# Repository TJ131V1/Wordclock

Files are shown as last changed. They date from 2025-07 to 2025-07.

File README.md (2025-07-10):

## 💡 Project Description

**This repository contains all the files for my custom word clock project, inspired by QLOCKTWO EARTH 45.**
The clock is a fully functional, physical word-based timepiece built from scratch and controlled by an Arduino Nano. It includes four hidden capacitive touch sensors. In addition to telling the time, it features:

- Snake game

- Tetris game

- LED visual effects including custom scrolling text, Conway’s Game of Life, Matrix rain, and a random letter decay animation

The repository includes:

- **Arduino Code** – All source code for the microcontroller

- **KiCAD Files** – Complete circuit schematic and PCB layout

- **2D Cutting Files** – Laser-cut design files for the structural components

- **Technical Report** – In-depth 10-page report detailing the project design, implementation, and build process

## 📽️ Showcase Video (Click Thumbnail to View)

Watch the video (https://youtu.be/x_0dHoGPLj4)

## 📸 Product Pictures

<p align="center">

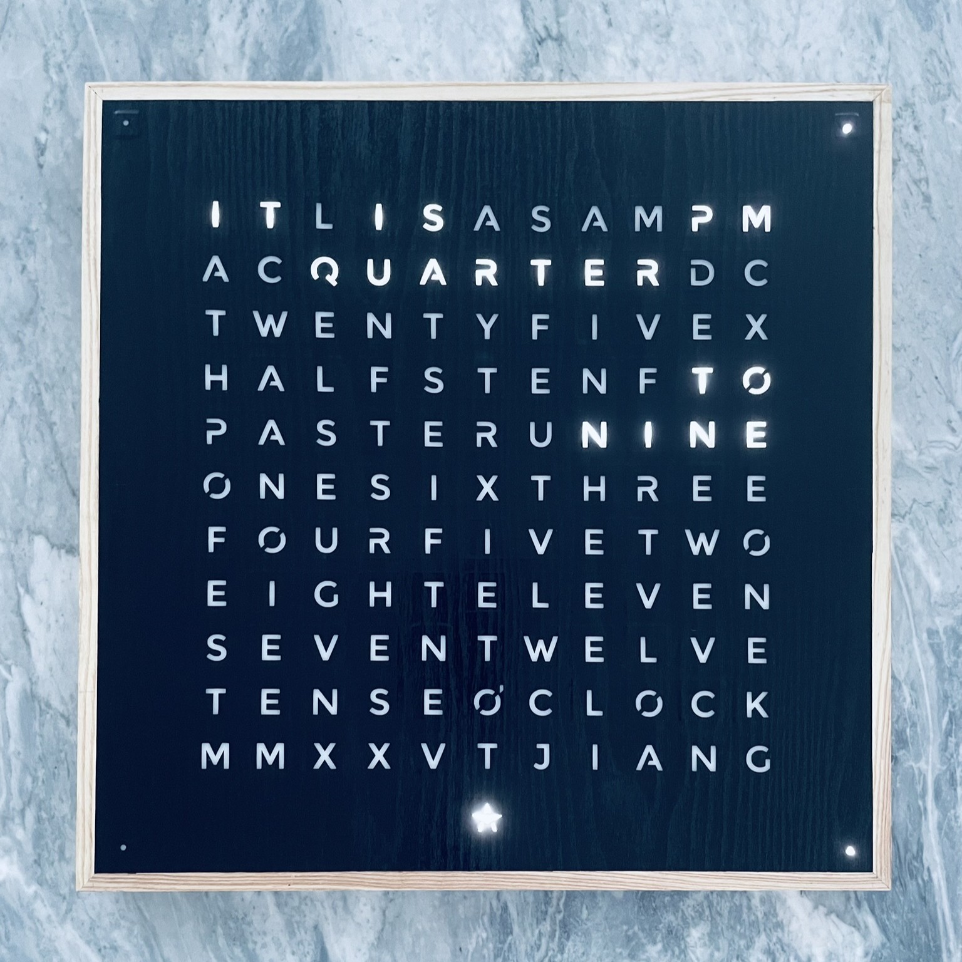
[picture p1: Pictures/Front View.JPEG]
Front view of the word clock
  

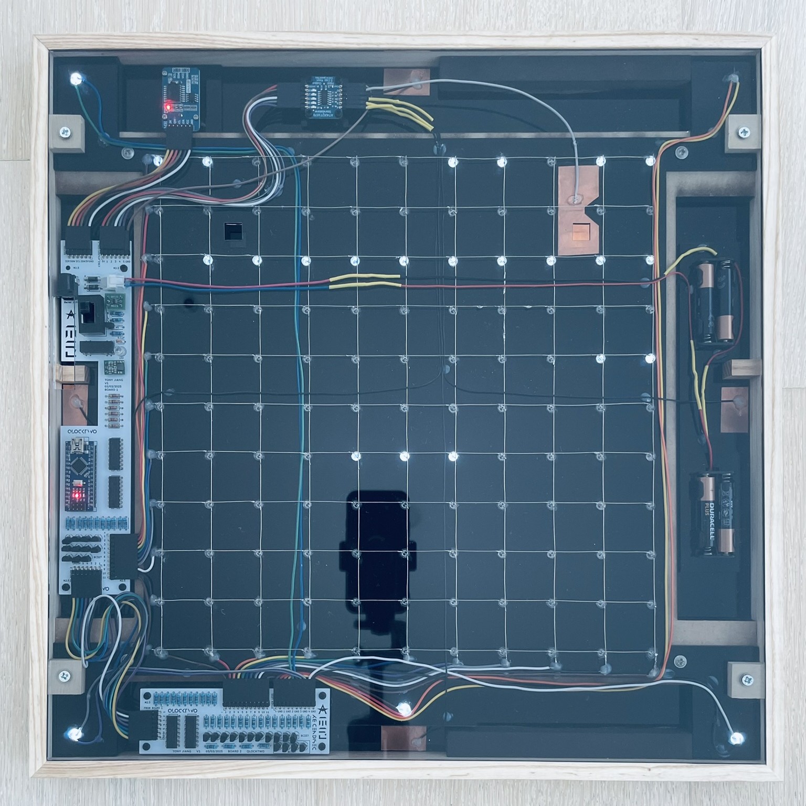
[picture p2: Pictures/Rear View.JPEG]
Rear view of the word clock
  

</p>

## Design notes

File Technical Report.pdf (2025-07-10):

Paper Produced for Institution of Electronics

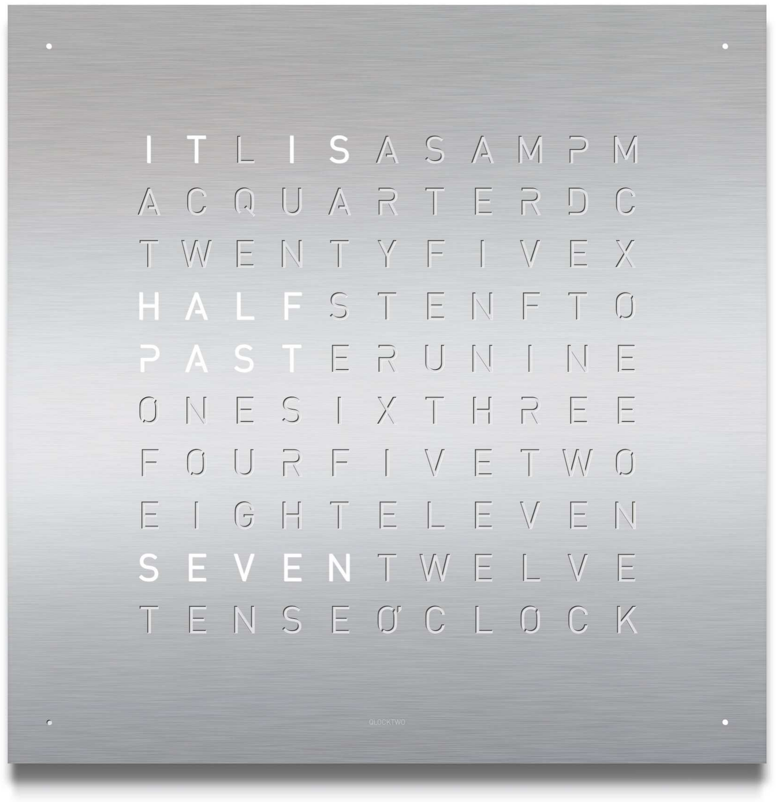
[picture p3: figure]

Tony Jiang, Winchester College, Winchester | Page 1

## An Arduino Word Clock

Tony Jiang, Winchester College, Winchester, Hampshire, SO23 9NA

### 1. Introduction

This project was a personal initiative that I undertook in my spare time between January and July 2025. At my school, there was a gifted QLOCKTWO EARTH 45 (a designer word clock) mounted on the wall. However, it had been non-functional for over five years. Only a few sta2 members recalled ever seeing it in operation; for most, it appeared to be nothing more than a decorative object. I discovered that the cost of professional repair was prohibitively high, to the extent that purchasing a new unit would be more economical. This realization motivated me to design and build my own word clock, incorporating custom features and functionality, all at a fraction of the commercial price. My goal was to install my fully functioning version at the school as a practical and symbolic replacement.

Figure 1.1 shows a QLOCKTWO EARTH 45 STAINLESS STEEL, the same model present at my school.¹

### 2. The Problem to be Solved

This project aims to design and manufacture a 45 × 45 cm word clock that not only displays the time but also incorporates a range of custom features. These include the ability to play classic games such as Snake and Tetris on its LED matrix, as well as the capability to show scrolling text and dynamic LED e2ects for aesthetic purposes. Achieving this functionality requires precise control of each individual LED within the matrix, along with a reliable timekeeping system that can maintain accuracy even when the device is disconnected from a power source. To enhance usability and flexibility, the clock is designed to operate on both battery and mains power. Interactive features are enabled through the integration of appropriate input sensors.

Tony Jiang, Winchester College, Winchester | Page 2

In addition to functionality, aesthetic considerations play an important role in the design. The target thickness for the final product is less than 25 mm, closely aligning with the original
QLOCKTWO design, which has a main body thickness of approximately 20 mm. It is worth noting that the QLOCKTWO also includes a secondary, smaller rear housing — presumably containing the microprocessor and other electronics — which may allow for a slimmer front profile. This project aims to achieve a similarly sleek form factor while housing all required components internally.

### 3. Research

### 3.1 LED Control

Controlling each individual LED in the matrix is a central technical challenge in this project. Through online research, I found that a common approach involves configuring the matrix so that the rows act as anodes and the columns as cathodes. This setup enables the use of multiplexing — a technique where only one row (or column) is activated at a time, while rapidly cycling through all rows (or columns) fast enough that, due to persistence of vision, it appears as though all desired LEDs are lit simultaneously.

The original QLOCKTWO uses a 10×11 LED matrix to accommodate all the necessary words. In my design, I have employed an 11×11 LED matrix to create a more symmetrical display and to provide additional space for customizing the letters. However, this larger matrix requires 22 I/O ports for direct control — 11 for the rows and 11 for the columns. The Arduino Nano unfortunately o2ers only 14 digital I/O pins, many of which are reserved for other functions. To address this limitation, I will use shift registers such as the 74HC595 to expand the number of available outputs. Each 74HC595 shift register controls 8 outputs while requiring only 3 Arduino pins (data, clock, and latch). However, an additional I/O pin is needed to control the shift registers’ clear (reset) line. By daisy-chaining two pairs of shift registers — one pair dedicated to the rows and the other to the columns — I will be able to control up to 32 outputs using just 7 Arduino pins. This configuration enables e2icient and scalable management of the 121 LEDs in the matrix while conserving valuable I/O resources on the microcontroller.

The word clock also includes five additional LEDs: one for illuminating the logo and four at the corners to indicate the minute modulus (as the matrix displays time in 5-minute intervals). Since I have unused outputs on the shift registers, I connected the corner LEDs to these outputs. I also decided that the logo LED should be wired directly to the microcontroller to simplify the coding.

### 3.2 Timekeeping

To ensure accurate timekeeping, I chose to use a separate RTC (Real-Time Clock) module with its own battery backup, as recommended by online research. The module communicates with the microcontroller via I²C and maintains accurate time even when the main power is disconnected. I

chose the AZ-Delivery DS3231, as it was readily available on Amazon.

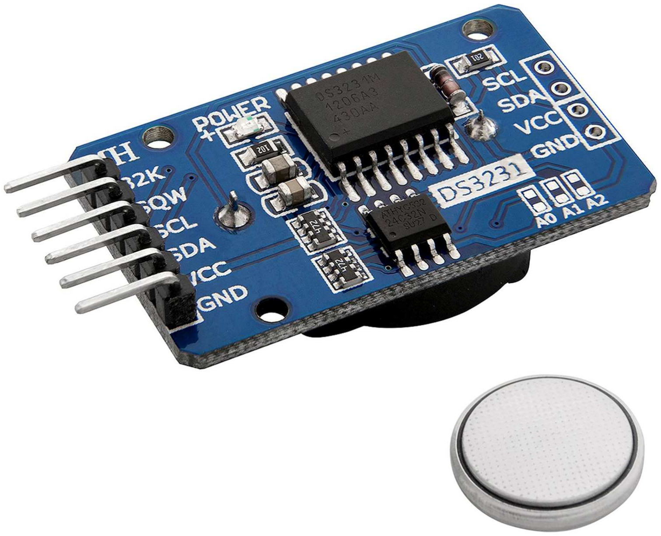
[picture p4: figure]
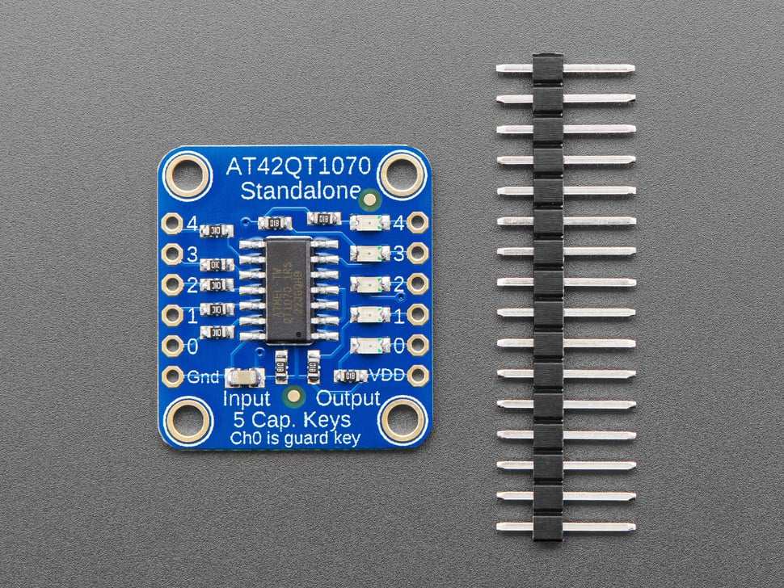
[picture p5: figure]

Tony Jiang, Winchester College, Winchester | Page 3

Figure 3.1 shows the AZ-Delivery DS3231 Real-Time Clock (RTC) module, with its 3.3V battery.²

### 3.3 Input Sensor

To enable gameplay features such as Snake and Tetris, I will need four input buttons positioned near the edges of the word clock. For aesthetic reasons, I want these buttons to remain hidden from view. Recalling that some lamps use touch-sensitive controls, I researched ways to implement invisible inputs and quickly discovered the presence of capacitive touch sensors.

Capacitive touch sensors detect changes in capacitance caused by a conductive object. When a finger nears the surface, it alters the local electric field, which the sensor detects and registers as a touch input. Looking for ways to implement this in my project, I found the Adafruit AT42QT1070 5-Pad Capacitive Touch Sensor. This standalone module communicates with the microcontroller via parallel output, pulling the corresponding channel LOW upon detection of a touch, making it straightforward to integrate into my design. I simply need to attach copper plates to the reverse side of the surface where input is desired and connect the plates to the sensor chip.

Figure 3.2 shows the Adafruit AT42QT1070 Standalone 5-Pad Capacitive Touch Sensor.³

### 3.4 Power

Since the 126-LED word clock must operate on both battery and mains power, a dedicated voltage regulator separate from the Arduino Nano is necessary. The Arduino cannot directly power such a large number of LEDs. I selected the Pololu 5V 1A Step-Up/Step-Down Voltage Regulator (S13V10F5), which provides a stable 5V output from input voltages ranging between 3V and 22V. For the battery, I plan to use four AAA cells in series. To protect the circuit from damage caused by excessive battery drain, a voltage supervisor is required to disconnect power when voltage falls below a safe threshold. I chose the Texas Instruments TPS3710 IC for this function. The TPS3710

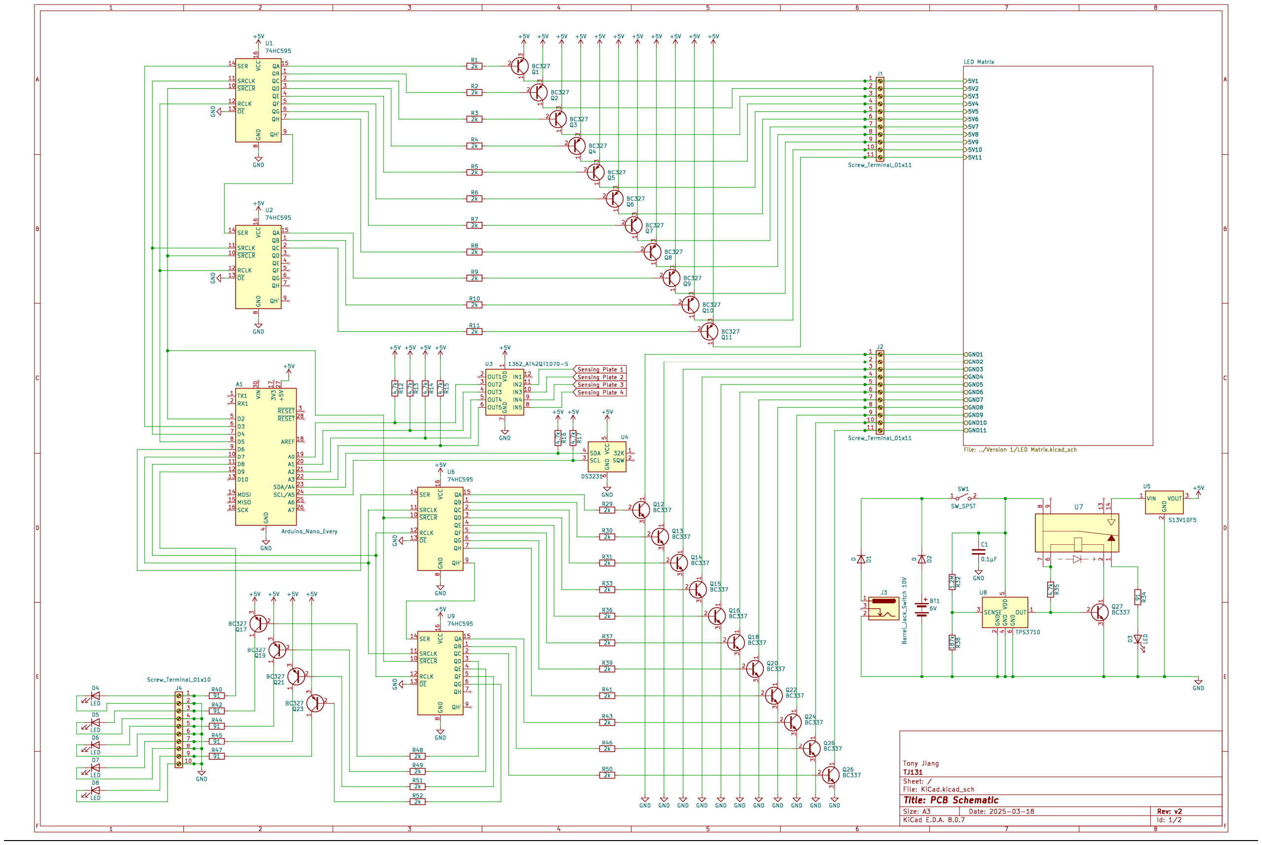
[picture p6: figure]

Tony Jiang, Winchester College, Winchester | Page 4

outputs a LOW signal when the input voltage falls below a pre-set threshold. When integrated into a custom circuit, this output can be used to disconnect the circuit.

### 4. Design and Build

### 4.1 Schematic

Figure 4.1 shows the schematic of the entire word clock.

Each LED in the matrix is arranged such that all anodes in a given row are soldered together, and all cathodes in a given column are connected. A PNP transistor is placed before each row to switch the row on or o2, while an NPN transistor is placed after each column to switch the column on or o2. This configuration allows control of any individual LED by activating its corresponding row and column transistors. It also enables each LED to draw current directly from the power source, while still being controlled via the Arduino.

Although the LEDs are rated for 3V, they are powered at 5V because multiplexing across the 11×11 matrix limits the time each LED is active, e2ectively reducing the average current through each one by a factor of 11. All LEDs are therefore wired in parallel to the 5V line.

Each transistor base is controlled by a 74HC595 shift register, which converts the Arduino’s serial output into parallel control signals. A 2 kΩ resistor is placed between each shift register output and transistor base to limit base current and protect the components.

Tony Jiang, Winchester College, Winchester | Page 5

A similar PNP-based switching method is used to control the four corner LEDs, which indicate minutes between the five-minute intervals. However, since these LEDs are not multiplexed, a 91 Ω resistor is added to each to keep the current within safe limits. The logo LED is connected directly to an Arduino I/O pin, also with a 91 Ω resistor for current limiting.

The RTC module (DS3231) requires two additional ports — Serial Data (SDA) and Serial Clocl (SCL) — for communication via the I²C protocol. I²C is an open-drain communication protocol where

devices can only pull the line LOW; HIGH signals are achieved through external pull-up resistors, which ensure the lines return to a HIGH state when not being pulled LOW. Although the DS3231 module includes built-in pull-up resistors, I added external ones in my circuit as an extra precaution to ensure signal reliability.

The remaining Arduino I/O ports are connected to the Adafruit AT42QT1070 capacitive touch sensor. Although the chip supports five inputs, I only required four sensor plates — one for each invisible button — so I connected four of its output lines to the Arduino. As mentioned earlier, the sensor uses open-drain outputs: it pulls the corresponding line LOW when a touch is detected. To ensure the lines return to a HIGH state when not pulled LOW, I added external pull-up resistors to each connection.

In total, I used 14 signal pins on the Arduino: 8 for the LEDs, 2 for the RTC module, and 4 for the capacitive touch sensor.

The final part of the circuit is the power module, located in the bottom corner of Figure 4.1. The S13V10F5 regulator converts any input voltage between 3V and 22V into a stable 5V output. A reed relay (U7) is used to disconnect the power supply from the main circuit if the input voltage drops too low. This cuto2 mechanism is controlled by the TPS3710 voltage monitor, which constantly measures the voltage at its SENSE pin. If the sensed voltage falls below 0.4V, the TPS3710 pulls its open-drain OUT pin LOW. To ensure the OUT pin returns to a HIGH state when not asserted, a pull-up resistor is required.

Since the TPS3710 only detects whether the voltage is above or below 0.4V, a potential divider is used to scale the input voltage accordingly. By selecting resistor values that make the SENSE pin read exactly 0.4V when the input voltage reaches the desired cuto2 threshold, the TPS3710 can e2ectively monitor supply levels. The appropriate resistor values were calculated using equations from the Texas Instruments application report⁴

and the TPS3710 datasheet⁵ , rounded to the
nearest standard resistor values.
-=

|%

100

− 1

=

3.00V 1
100

# 25nA 3.00V

0.400V − 1

= 185kΩ | 4.1!

" = -#

# − 1$ = 185kΩ # 3.00V

0.400V − 1$ = 1.2MΩ | 4.2!

When used in conjunction with an NPN transistor, this circuit cuts o2 current to the relay coil if the input voltage is too low, because when the OUT pin is asserted (pulled LOW), the transistor is switched o2, preventing current from flowing through the relay magnet. This causes the reed switch to disconnect the main circuit and instead complete a path to an LED, which lights up to

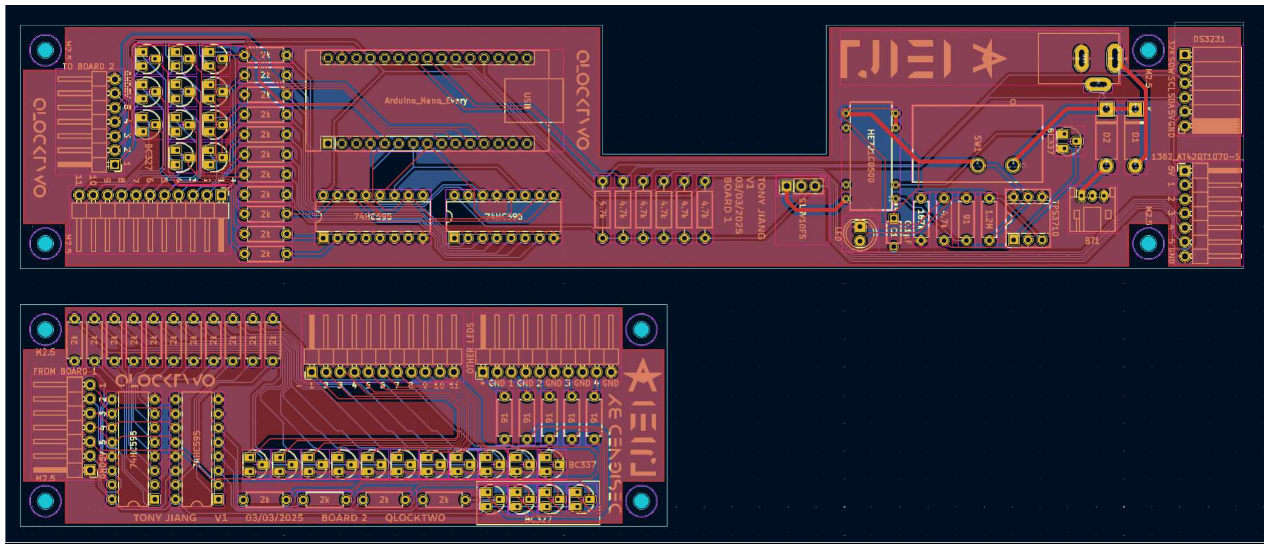
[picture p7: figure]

Tony Jiang, Winchester College, Winchester | Page 6

indicate that the input voltage has fallen below the threshold — either due to low mains voltage or a depleted battery.

### 4.2 PCB Layout

Figure 4.2 illustrates the layout of the custom PCB manufactured for the word clock.

The components from the schematic are distributed across two custom-designed PCB boards. The main challenge in the PCB layout was fitting all components within the limited internal space of the word clock, which has a maximum thickness of 25 mm. The central area is occupied by the LED matrix, leaving only narrow strips along the four edges for electronics. Additionally, the presence of corner LEDs and capacitive touch pads further reduces the space available to mount the PCB boards. On Board 1, there is a central cutout in the PCB to accommodate a copper plate acting as a touch sensor, located at the midpoint of each edge. Various pin headers connect the PCB to the rest of the components:

- On Board 1, the two right-side pin header rows connect the Arduino to the RTC module and capacitive touch sensor.
- The header orientated downwards on Board 1 connects to the anodes of the LED matrix.
- The left-side headers on both boards are wired together to allow communication between the boards.
- On Board 2, the headers oriented upwards connect to the cathodes of the LED matrix and the five additional LEDs (four minute indicators and the logo LED).

The PCB Gerber files were sent to JLCPCB for physical fabrication, which arrived by post within a week.

### 4.3 Physical Fabrication

The physical fabrication of the product primarily involved laser cutting, supplemented by some woodworking for structural components.

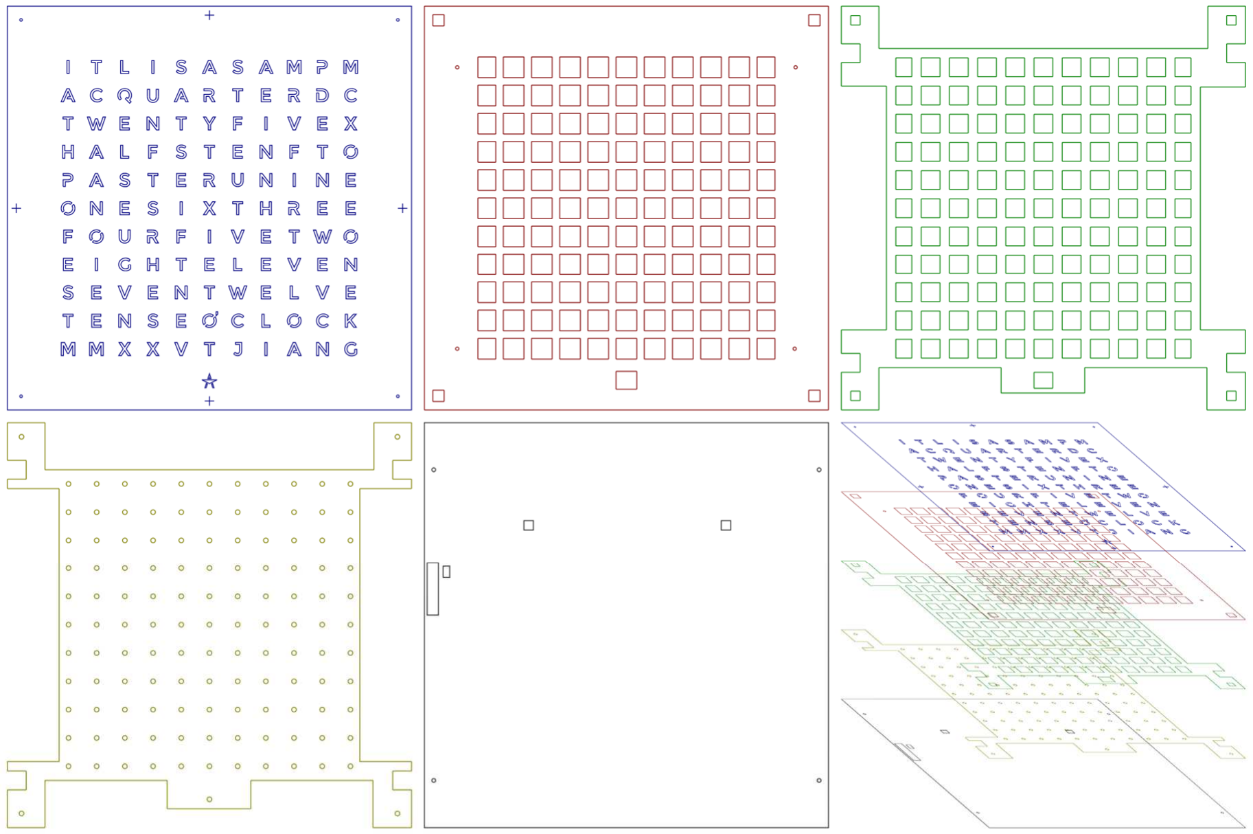
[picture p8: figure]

Tony Jiang, Winchester College, Winchester | Page 7

Figure 4.3 illustrates the various structural layers of the word clock. The clock consists of a 0.5 mm vinyl faceplate (blue), 3 mm acrylic light-di2user layer (red), 9 mm MDF structural layer (green), 3mm acrylic
LED structure layer (yellow), and a 3mm back plate (black).

Figure 4.3 shows all the laser-cut layers used in the construction of the word clock. The top blue layer is a sheet of black woodgrain-patterned vinyl with cut-out letters. The cut-out letters are based on the Montserrat font, which I customized to ensure no islands appear within the letters.

The blue layer is adhered to the red layer beneath it, which is made from 3 mm black acrylic with letter-shaped cutouts filled with 3 mm semi-transparent white acrylic. This combination acts as a di2user, helping to evenly distribute the light from the LEDs below each letter.

The green layer is a 9 mm MDF structural component. It creates the necessary spacing between the di2user and the LED matrix and provides mounting points for both the red and yellow layers via screws.

The yellow layer is a 3 mm acrylic jig that accurately holds each LED in place within its designated hole.

At the back, the black layer is a 3 mm clear acrylic panel that protects the internal electronics. It includes holes for wall-mounting screws and a cutout on the left-hand side for a switch.

Additionally, four wooden support blocks are glued to the red layer and are slotted into cutouts in the green and yellow layers. These blocks allow the back panel to be securely screwed in while maintaining an air gap between the yellow and black layers — providing essential space for wiring and other electronics.

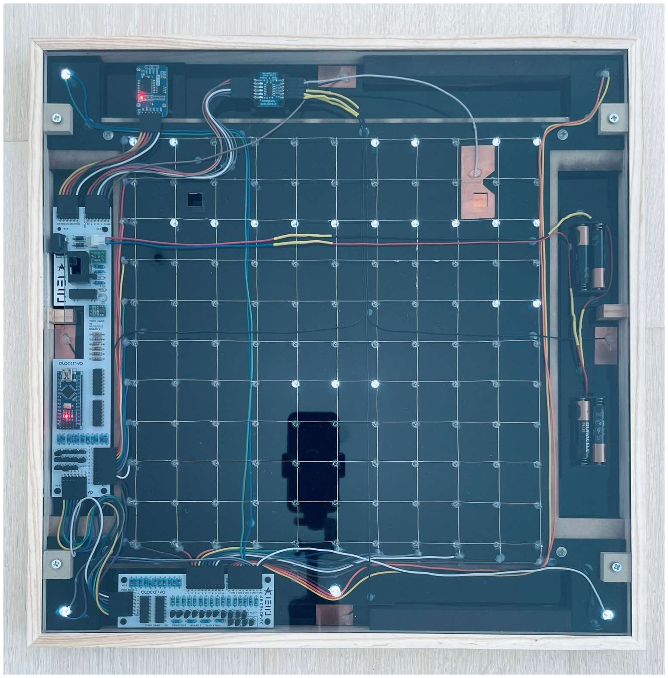
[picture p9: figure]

Tony Jiang, Winchester College, Winchester | Page 8

Lastly, a 10 mm thick ash wood frame is built around the clock, joined at the corners with mitre joints. This frame protects the entire structure from the sides and gives it a clean, finished look. The electronic components are mounted in the narrow spaces along the edges of the clock. Wires are soldered to connect the PCBs to the LEDs and copper touch plates. To keep the wiring secure and organized, hot glue is used to fix the wires in place. The internal layout of the electronics is shown in Figure 4.4, which is a backside view of the finished product.

Figure 4.4 shows the rear side of the completed word clock while in clock mode.

### 4.4 Code

Unfortunately, the full C++ code for this project exceeds 1,000 lines and cannot be fully explained within this document. However, the complete commented code — along with all CAD and design files — is available on the project’s GitHub page: https://github.com/TJ131V1/Wordclock.

In short, the code supports four main functions: time display, Snake, Tetris, and various LED e2ects. Long pressing the respective copper touch plates switches between modes. The same plates serve as control inputs for Snake and Tetris. In LED e2ects mode, users can toggle between several animations: Conway’s Game of Life, a Matrix-style rain e2ect, a random letter decay, and a scrolling text display (the text can be modified in the code).

### 5. Evaluation of Final Product

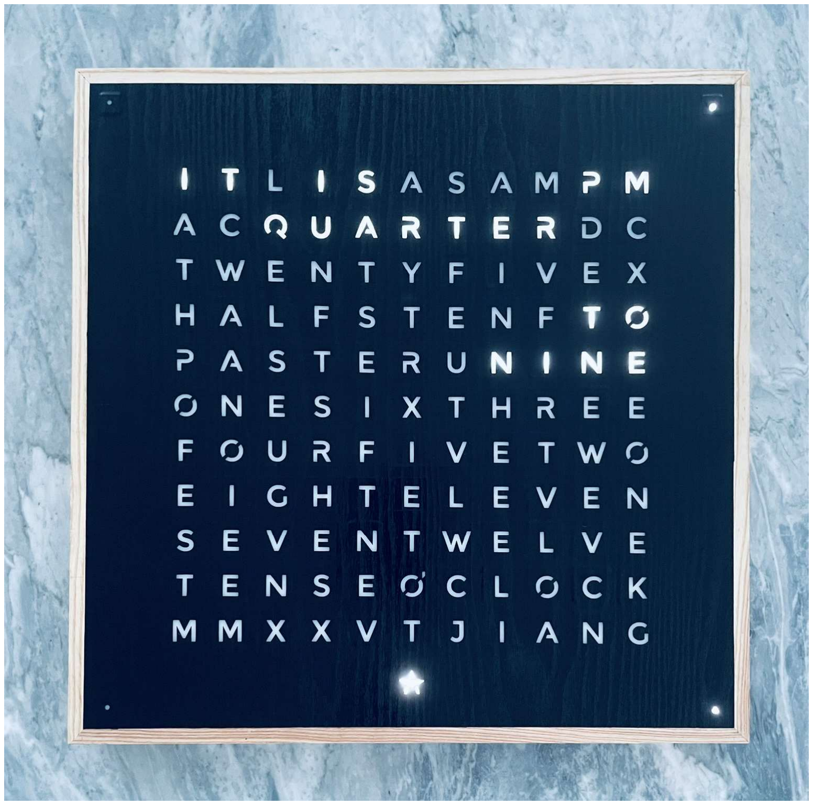
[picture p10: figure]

Tony Jiang, Winchester College, Winchester | Page 9

Figure 5.1 shows the front of the completed word clock, displaying the time 8:47 in clock mode.

The final product has a total thickness of exactly 25 mm, precisely meeting the original design specification. The front display is clean and aesthetically pleasing, and the timekeeping is highly accurate — only about one second behind the actual time. The capacitive touch buttons are extremely well hidden, making them virtually undetectable without prior knowledge of their placement. Gameplay for Snake and Tetris is smooth and responsive, o2ering a satisfying user experience. The various LED e2ects add dynamic visual interest, making the clock an eye-catching decorative piece when mounted. The ability to switch modes using capacitive touch sensors enhances usability and creates a seamless, intuitive interface. Overall, I’m very satisfied with the additional features beyond timekeeping — they make the clock both functional and engaging.

The PCB components cost approximately £40. Fabricating the PCB board cost £25 for a minimum batch of five, so in commercial production, the cost per clock would be under £5. The structural components were free, as I fabricated them at my school, but the materials used — acrylic sheets, MDF, and ash dowel — would likely cost under £20. Laser cutting is estimated at around £150 total. Altogether, this brings the total cost per clock to under £200, which is roughly 13% of the price of a QLOCKTWO EARTH 45.

### 6. Recommendations for Future Work

In hindsight, using multiplexing as the core architecture was not the best design choice. A chain of addressable LEDs would have greatly simplified both the schematic and PCB layout by eliminating

Tony Jiang, Winchester College, Winchester | Page 10

the need for shift registers and numerous transistors. Although more expensive than standard white LEDs, addressable LEDs o2er major advantages: full RGB colour control, much higher brightness, and more consistent illumination. In the current clock, the centres of the letters are noticeably brighter than the edges, and the display is di2icult to read in bright daylight — issues that brighter LEDs would solve. They would also drastically reduce code complexity. The primary reason for the lengthy code is the complexity introduced by the multiplexing architecture.

I also underestimated the small size of the TPS3710’s SOT-6 package (just 2.8 × 2.9 mm), which made soldering di2icult and time-consuming. For future revisions or commercial production, I would use a voltage supervisor in a larger DIP package.

Additionally, the clock should adjust for daylight saving time automatically, using date information from the RTC to stay accurate year-round in the UK.

Finally, the four AAA batteries only last around two hours. Switching to AA batteries would greatly improve runtime.

### 7. Acknowledgments

I would like to express my gratitude to Winchester College for providing access to the Design and Technology facilities. I am also sincerely thankful to the D&T teachers and technicians — Callum Barnes, Adrian Ahmed, Trevor Ward, and David Salter — for their invaluable support and guidance throughout the physical fabrication of this project.

### 8. References

1. QLOCKTWO Earth 45 Stainless Steel Wall Clock Watch QT4ENSS Watch | Jura Watches.

https://www.jurawatches.co.uk/products/qlocktwo-classic-stainless-steel-wall-clock-45cm-

fcenss.

2. Real Time Clock RTC DS3231 I2C Echtzeituhr kompatibel mit Arduino und Raspberry Pi. AZ-

Delivery https://www.az-delivery.uk/products/ds3231-real-time-clock.

3. Adafruit Industries Standalone 5-Pad Capacitive Touch Sensor Breakout - AT42QT1070.

https://www.adafruit.com/product/1362.

4. Fagnani, A. IQ vs Accuracy Tradeo2 In Designing Resistor Divider Input To A Voltage Supervisor.

(2011).

5. TPS3710 Wide VIN Voltage Detector datasheet (Rev. A). (2024).

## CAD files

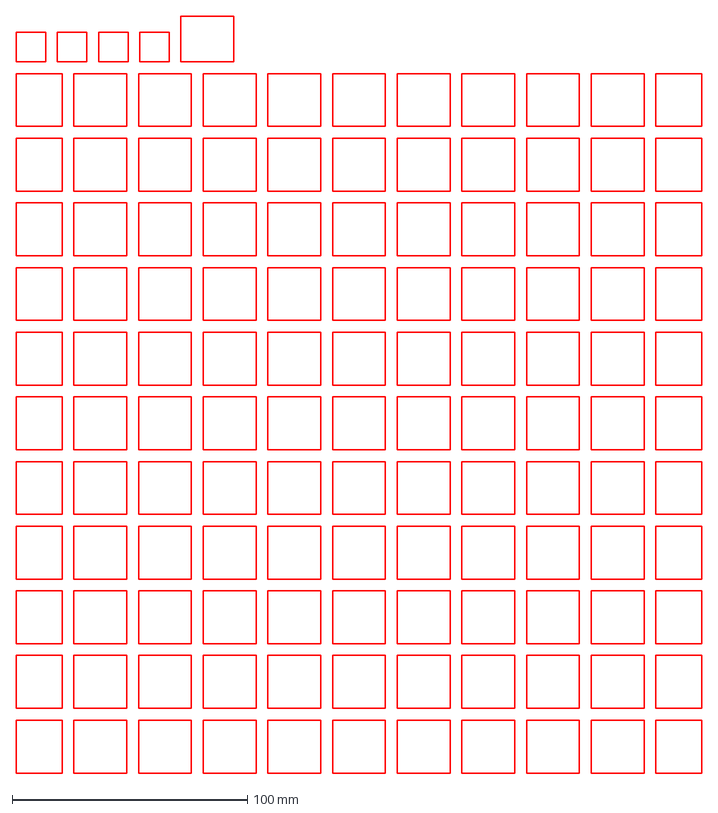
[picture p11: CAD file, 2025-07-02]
2D Cutting Files/LED Diffuser.dxf
291.5 x 322.0 mm

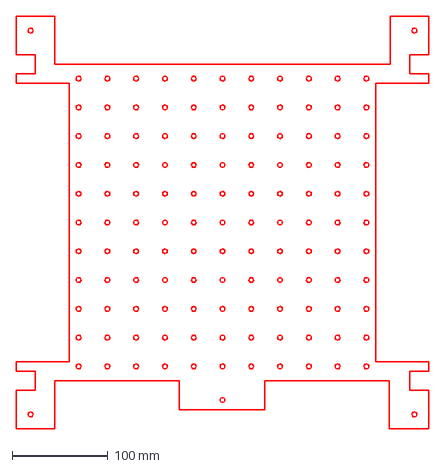
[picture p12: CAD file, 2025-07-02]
2D Cutting Files/LED Acrylic Jig.dxf
430.0 x 430.0 mm

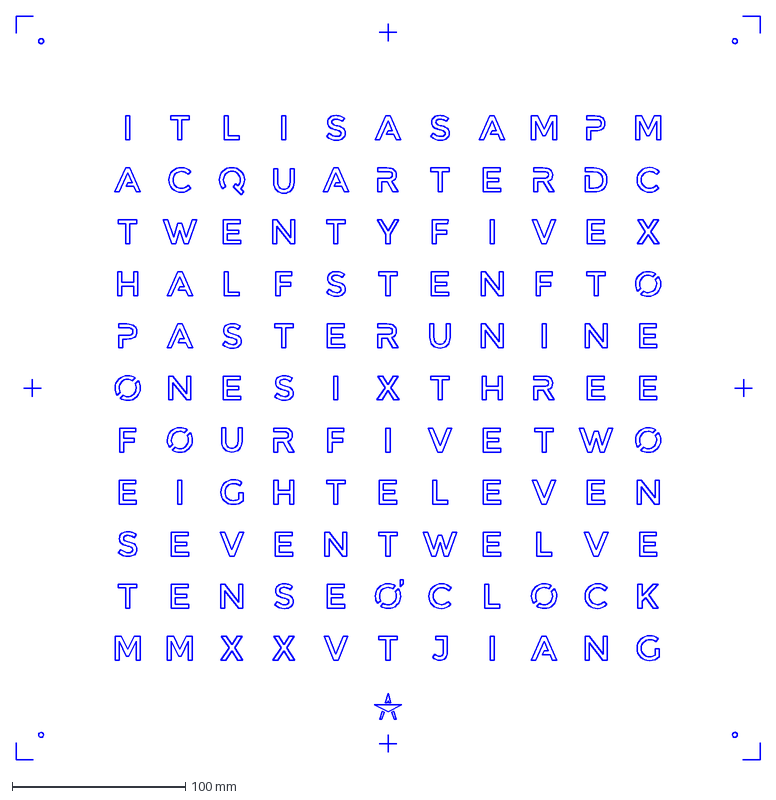
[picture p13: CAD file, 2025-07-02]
2D Cutting Files/Faceplate Vinyl.dxf
429.0 x 429.0 mm

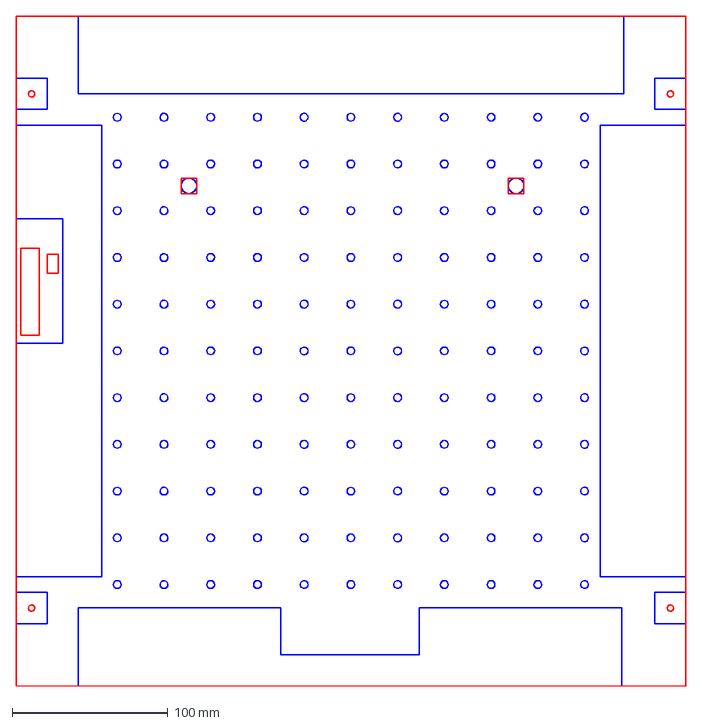
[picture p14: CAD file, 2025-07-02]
2D Cutting Files/Back Acrylic Layer.dxf
430.1 x 430.1 mm

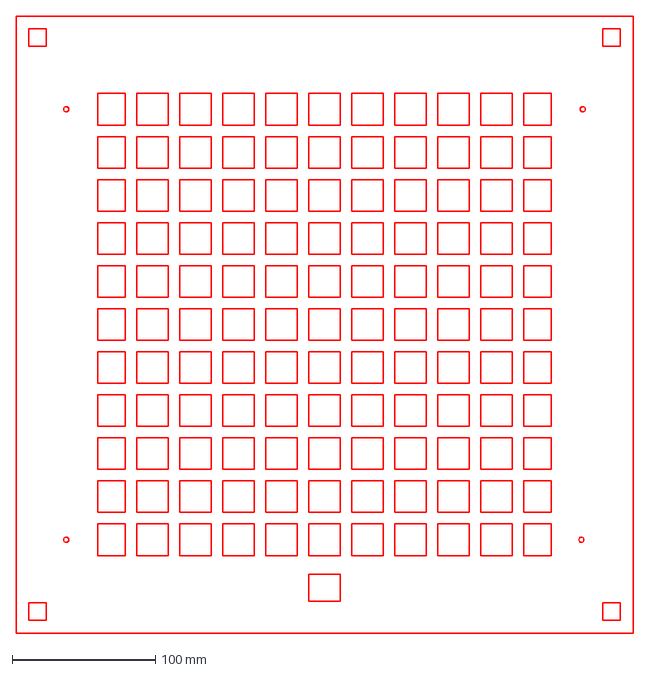
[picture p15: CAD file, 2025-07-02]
2D Cutting Files/Front Acrylic Layer.dxf
430.0 x 430.0 mm

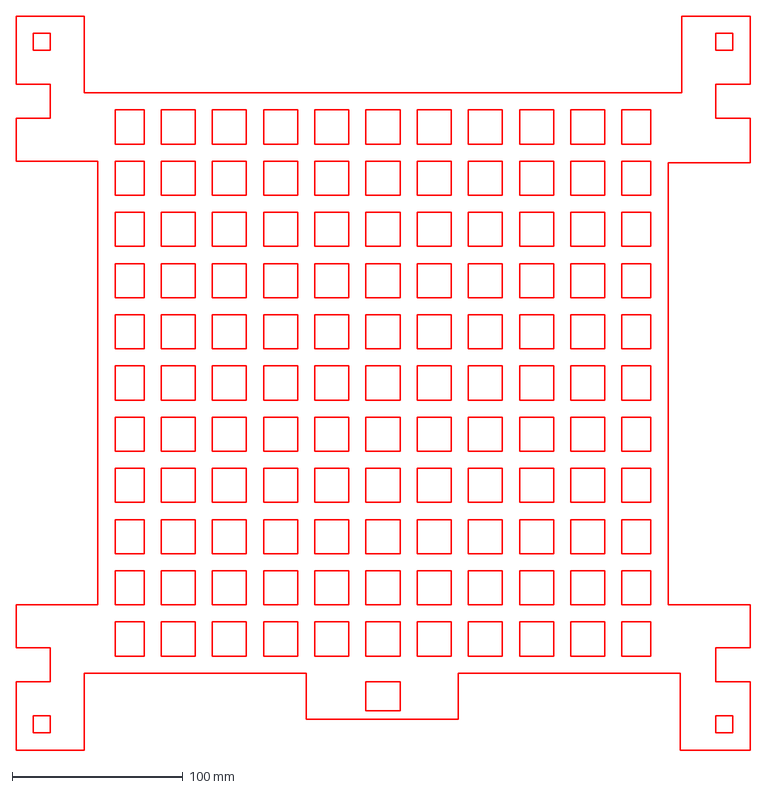
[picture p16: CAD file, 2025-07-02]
2D Cutting Files/Middle MDF Layer.dxf
430.0 x 430.0 mm

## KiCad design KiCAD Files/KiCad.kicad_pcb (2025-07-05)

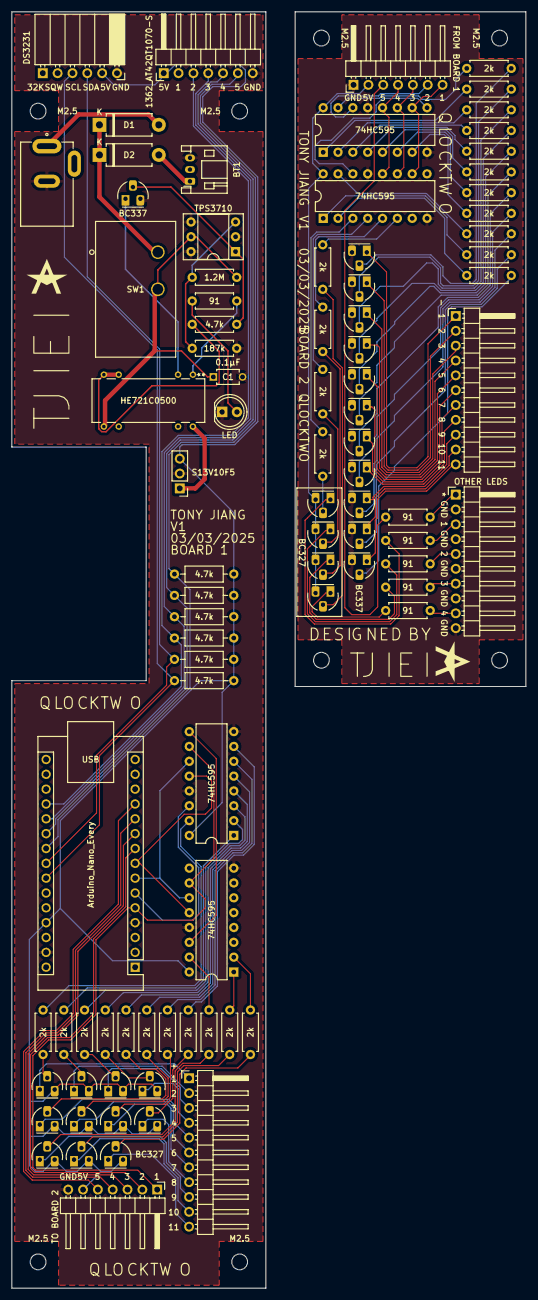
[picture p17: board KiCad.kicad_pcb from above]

Board: 2 copper layers, 88.0 x 218.5 mm, 96 parts (0 on the bottom side), 112 nets.

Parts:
A1: Arduino_Nano_Every; Arduino_Nano
BT1: 6V; JST_PH_S3B-PH-K_1x03_P2.00mm_Horizontal
C1: 0.1µF; C_K104K10X7RF5UH5_VIS
D1, D2: D; D_DO-15_P10.16mm_Horizontal
D3: LED; LED_D5.0mm
J1, J2: Screw_Terminal_01x11; PinHeader_1x11_P2.54mm_Horizontal
J3: Barrel_Jack_Switch 10V; BarrelJack_CUI_PJ-002B_Horizontal
J4: Screw_Terminal_01x10; PinHeader_1x10_P2.54mm_Horizontal
M2.5, M2.5#2, M2.5#3, M2.5#4, M2.5#5, M2.5#6, M2.5#7, M2.5#8: MountingHole_2.7mm_M2.5
Q1, Q2, Q3, Q4, Q5, Q6, Q7, Q8, Q9, Q10, Q11, Q17, Q19, Q21, Q23: BC327; TO-92_Inline_Medium
Q12, Q13, Q14, Q15, Q16, Q18, Q20, Q22, Q24, Q25, Q26, Q27: BC337; TO-92_Inline_Medium
R1, R2, R3, R4, R5, R6, R7, R8, R9, R10, R11, R29, R30, R31, R33, R36, R37, R39, R41, R43, R46, R48, R49, R50, R51, R52: 2k; R_Axial_DIN0207_L6.3mm_D2.5mm_P7.62mm_Horizontal
R12, R13, R14, R15, R16, R17: 4.7k; R_Axial_DIN0207_L6.3mm_D2.5mm_P10.16mm_Horizontal
R32: 1.2M; R_Axial_DIN0207_L6.3mm_D2.5mm_P7.62mm_Horizontal
R34, R40, R42, R44, R45, R47: 91; R_Axial_DIN0207_L6.3mm_D2.5mm_P7.62mm_Horizontal
R35: 4.7k; R_Axial_DIN0207_L6.3mm_D2.5mm_P7.62mm_Horizontal
R38: 187k; R_Axial_DIN0207_L6.3mm_D2.5mm_P7.62mm_Horizontal
SW1: SW_SPST; SW_SPST_S101031MS02Q_CNK
U1, U2, U6, U9: 74HC595; DIP-16_W7.62mm
U3: 1362_AT42QT1070-S; PinHeader_1x07_P2.54mm_Horizontal
U4: DS3231; PinSocket_1x06_P2.54mm_Horizontal
U5: S13V10F5; PinHeader_1x03_P2.54mm_Vertical
U7: HE721C0500; Relay_SPDT_HE700_LTF
U8: TPS3710; DIP-6_W7.62mm_Socket

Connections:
+5V: A1.27 (+5V), Q1.3 (E), Q2.3 (E), Q3.3 (E), Q4.3 (E), Q5.3 (E), Q6.3 (E), Q7.3 (E), Q8.3 (E), Q9.3 (E), Q10.3 (E), Q11.3 (E), Q17.3 (E), Q19.3 (E), Q21.3 (E), Q23.3 (E), R12.1, R13.1, R14.1, R15.1, R16.1, R17.1, U1.16 (VCC), U2.16 (VCC), U3.1 (VDD), U4.5 (VCC), U5.3 (VOUT), U6.16 (VCC), U9.16 (VCC)
/LED Matrix/5V1: J1.1, Q1.1 (C)
/LED Matrix/5V2: J1.2, Q2.1 (C)
/LED Matrix/5V3: J1.3, Q3.1 (C)
/LED Matrix/5V4: J1.4, Q4.1 (C)
/LED Matrix/5V5: J1.5, Q5.1 (C)
/LED Matrix/5V6: J1.6, Q6.1 (C)
/LED Matrix/5V7: J1.7, Q7.1 (C)
/LED Matrix/5V8: J1.8, Q8.1 (C)
/LED Matrix/5V9: J1.9, Q9.1 (C)
/LED Matrix/5V10: J1.10, Q10.1 (C)
/LED Matrix/5V11: J1.11, Q11.1 (C)
/LED Matrix/GND1: J2.1, Q12.1 (C)
/LED Matrix/GND2: J2.2, Q13.1 (C)
/LED Matrix/GND3: J2.3, Q14.1 (C)
/LED Matrix/GND4: J2.4, Q15.1 (C)
/LED Matrix/GND5: J2.5, Q16.1 (C)
/LED Matrix/GND6: J2.6, Q18.1 (C)
/LED Matrix/GND7: J2.7, Q20.1 (C)
/LED Matrix/GND8: J2.8, Q22.1 (C)
/LED Matrix/GND9: J2.9, Q24.1 (C)
/LED Matrix/GND10: J2.10, Q25.1 (C)
/LED Matrix/GND11: J2.11, Q26.1 (C)
GND: A1.4 (GND), A1.29 (GND), BT1.3 (-), C1.2, D3.1 (K), J3.2, J4.2, J4.4, J4.6, J4.8, J4.10, Q12.3 (E), Q13.3 (E), Q14.3 (E), Q15.3 (E), Q16.3 (E), Q18.3 (E), Q20.3 (E), Q22.3 (E), Q24.3 (E), Q25.3 (E), Q26.3 (E), Q27.3 (E), R38.2, U1.8 (GND), U1.13 (~OE), U2.8 (GND), U2.13 (~OE), U3.7 (GND), U4.6 (GND), U5.2 (GND), U6.8 (GND), U6.13 (~OE), U8.2 (GND), U8.4 (GND), U8.6 (GND), U9.8 (GND), U9.13 (~OE)
unnamed: A1.19 (A0), R12.2, U3.3 (OUT2)
unnamed: A1.20 (A1), R13.2, U3.4 (OUT3)
unnamed: A1.21 (A2), R14.2, U3.5 (OUT4)
unnamed: A1.22 (A3), R15.2, U3.6 (OUT5)
unnamed: A1.5 (D2), U1.10 (~SRCLR), U2.10 (~SRCLR), U6.10 (~SRCLR), U9.10 (~SRCLR)
unnamed: A1.6 (D3), U1.14 (SER)
unnamed: A1.7 (D4), U1.11 (SRCLK), U2.11 (SRCLK)
unnamed: A1.8 (D5), U1.12 (RCLK), U2.12 (RCLK)
unnamed: A1.9 (D6), U6.14 (SER)
unnamed: A1.10 (D7), U6.11 (SRCLK), U9.11 (SRCLK)
unnamed: A1.11 (D8), U6.12 (RCLK), U9.12 (RCLK)
unnamed: A1.12 (D9), R40.2
unnamed: A1.24 (SCL/A5), R17.2, U4.3 (SCL)
unnamed: A1.23 (SDA/A4), R16.2, U4.4 (SDA)
unnamed: BT1.1 (+), D2.2 (A)
unnamed: D1.2 (A), J3.1
unnamed: D1.1 (K), D2.1 (K), SW1.1 (A)
unnamed: D3.2 (A), R34.2
unnamed: J4.1, R40.1
unnamed: J4.3, R42.1
unnamed: J4.5, R44.1
unnamed: J4.7, R45.1
unnamed: J4.9, R47.1
unnamed: Q1.2 (B), R1.2
unnamed: Q2.2 (B), R2.2
unnamed: Q3.2 (B), R3.2
unnamed: Q4.2 (B), R4.2
unnamed: Q5.2 (B), R5.2
unnamed: Q6.2 (B), R6.2
unnamed: Q7.2 (B), R7.2
unnamed: Q8.2 (B), R8.2
unnamed: Q9.2 (B), R9.2
unnamed: Q10.2 (B), R10.2
unnamed: Q11.2 (B), R11.2
unnamed: Q12.2 (B), R29.2
unnamed: Q13.2 (B), R30.2
unnamed: Q14.2 (B), R31.2
unnamed: Q15.2 (B), R33.2
unnamed: Q16.2 (B), R36.2
unnamed: Q17.2 (B), R48.1
unnamed: Q17.1 (C), R42.2
unnamed: Q18.2 (B), R37.2
unnamed: Q19.2 (B), R49.1
unnamed: Q19.1 (C), R44.2
unnamed: Q20.2 (B), R39.2
unnamed: Q21.2 (B), R51.1
unnamed: Q21.1 (C), R45.2
unnamed: Q22.2 (B), R41.2
unnamed: Q23.2 (B), R52.1
unnamed: Q23.1 (C), R47.2
unnamed: Q24.2 (B), R43.2
unnamed: Q25.2 (B), R46.2
unnamed: Q26.2 (B), R50.2
unnamed: Q27.2 (B), R35.2, U8.1 (OUT)
unnamed: Q27.1 (C), U7.2
unnamed: R34.1, U7.1
unnamed: R35.1, U7.6, U7.7
unnamed: C1.1, R32.1, SW1.2 (B), U7.8, U8.5 (VDD)
unnamed: R1.1, U1.15 (QA)
unnamed: R2.1, U1.1 (QB)
unnamed: R3.1, U1.2 (QC)
unnamed: R4.1, U1.3 (QD)
unnamed: R5.1, U1.4 (QE)
unnamed: R6.1, U1.5 (QF)
unnamed: R7.1, U1.6 (QG)
unnamed: U1.9 (QH'), U2.14 (SER)
unnamed: R8.1, U1.7 (QH)
unnamed: R9.1, U2.15 (QA)
unnamed: R10.1, U2.1 (QB)
unnamed: R11.1, U2.2 (QC)
unnamed: U5.1 (VIN), U7.14
unnamed: R29.1, U6.15 (QA)
unnamed: R30.1, U6.1 (QB)
unnamed: R31.1, U6.2 (QC)
unnamed: R33.1, U6.3 (QD)
unnamed: R36.1, U6.4 (QE)
unnamed: R37.1, U6.5 (QF)
unnamed: R39.1, U6.6 (QG)
unnamed: U6.9 (QH'), U9.14 (SER)
unnamed: R41.1, U6.7 (QH)
unnamed: R32.2, R38.1, U8.3 (SENSE)
unnamed: R43.1, U9.15 (QA)
unnamed: R46.1, U9.1 (QB)
unnamed: R50.1, U9.2 (QC)
unnamed: R48.2, U9.3 (QD)
unnamed: R49.2, U9.4 (QE)
unnamed: R51.2, U9.5 (QF)
unnamed: R52.2, U9.6 (QG)

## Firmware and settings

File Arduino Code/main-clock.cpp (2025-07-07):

// Declare used libraries
#include <Arduino.h>
#include <Wire.h>
#include "RTClib.h"
#include <TimerOne.h>
#include <avr/pgmspace.h>

//Declare hardware pins
RTC_DS3231 rtc;
int clearpin = 2;
int Aserialdata = 3;
int Ashiftclock = 4;
int Alatchclock = 5;
int Bserialdata = 6;
int Bshiftclock = 7;
int Blatchclock = 8;
int starpin = 9;
int plateone = 14;
int platetwo = 15;
int platethree = 16;
int platefour = 17;

// Multiplexing archetecture variables
volatile int currentRow = 0;
int multiplextime = 0;             // Delay between multiplexing each row, initially used for testing
uint16_t tempRowData[11];
volatile uint16_t rowData[11];     // rowData holds information about which LEDs we want on from each row.
const uint16_t MINUTE_BITS_MASK = 0b1111100000000000; 
// In my hardware, all LEDs are controlled by a 16-digit binary number. 
// The five leftmost bits are my logo LED and the four corner LEDs. (1 = off, 0 = on)
// The remaining 11 bits are the 11 rows of LEDs. (1 = on, 0 = off)

// Determines the mode the word clock is in
int mode = 0;

// Touch sensor variables
unsigned long pressStart = 0;      // Time when plate press started
bool longPressHandled = false;     // True is plate is pressed for more than 3000 ms
int lastPlate = 0;                 // Plate previously held
int currentPlate = 0;              // Plate currently held
int shortPressedPlate = 0;         // Plate number of plate that was short pressed


// Function that clears all shift registers
void clear() {
    shiftOut(Bserialdata, Bshiftclock, LSBFIRST, 0B00011111);
    shiftOut(Bserialdata, Bshiftclock, LSBFIRST, 0B00000000);
    digitalWrite(Blatchclock, HIGH);
    digitalWrite(Blatchclock, LOW);
  }

// Function that latches the output of the shift registers
void latchOutput() {
    digitalWrite(Alatchclock, HIGH);
    digitalWrite(Blatchclock, HIGH);
    digitalWrite(Alatchclock, LOW);
    digitalWrite(Blatchclock, LOW);
}

// Function that poweres on a row based on its row number 'num'
void shiftOutMultiplex(int num) {
    shiftOut(Aserialdata, Ashiftclock, LSBFIRST, ~((0b10000000000 >> num) << 5));
    shiftOut(Aserialdata, Ashiftclock, LSBFIRST, ~((0b10000000000 >> num) >> 3));
}

// Core multiplexing function that cycles through each row at a time.
// All LEDs' anodes in a desired row is connected to 5V.
// Only desired LEDs' cathodes in that row is connected to GND.
// In this way, we can control which LEDs we want on in any row.
void multiplexInterruptHandler() {
    clear();  // clear display before switching row

    // Connects all anodes to 5V in a row
    shiftOutMultiplex(currentRow);

    // Get the 16-bit 'code' for this row from rowData. This 'code' tells us which LEDs in that row we want on (which cathodes to connect to GND).
    uint16_t value = rowData[currentRow];

    // Connects the desired cathodes to GND
    shiftOut(Bserialdata, Bshiftclock, MSBFIRST, (value >> 8) & 0xFF);  // upper 8 bits
    shiftOut(Bserialdata, Bshiftclock, MSBFIRST, value & 0xFF);         // lower 8 bits

    // Latches the output of the shift registers
    latchOutput();

    // Cycles through the rows in a loop
    currentRow++;
    if (currentRow >= 11) currentRow = 0;
}





// Mode 1 - Time

//Declaring mode-specific variables
static bool modeOneChanged = true;
int previousRoundedMin = 0;

// Locations on the LED matrix for words for the time display
#define WORD_AM             {0, 0b00000001100}   // row 0, bits 7-8
#define WORD_PM             {0, 0b00000000011}   // row 0, bits 9-10
#define WORD_IT             {0, 0b11000000000}   // row 0, bits 0-1
#define WORD_IS             {0, 0b00011000000}   // row 0, bits 3-4
#define WORD_QUARTER_MINUTE {1, 0b00111111100}   // row 1, bits 2-8
#define WORD_TWENTY_MINUTE  {2, 0b11111100000}   // row 2, bits 0-6
#define WORD_FIVE_MINUTE    {2, 0b00000011110}   // row 2, bits 6-9
#define WORD_HALF           {3, 0b11110000000}   // row 3, bits 0-4
#define WORD_TEN_MINUTE     {3, 0b00000111000}   // row 3, bits 5-7
#define WORD_TO             {3, 0b00000000011}   // row 3, bits 9-10
#define WORD_PAST           {4, 0b11110000000}   // row 4, bits 0-3
#define WORD_NINE_HOUR      {4, 0b00000001111}   // row 4, bits 7-10
#define WORD_ONE_HOUR       {5, 0b11100000000}   // row 5, bits 0-2
#define WORD_SIX_HOUR       {5, 0b00011100000}   // row 5, bits 3-5
#define WORD_THREE_HOUR     {5, 0b00000011111}   // row 5, bits 6-10
#define WORD_FOUR_HOUR      {6, 0b11110000000}   // row 6, bits 0-3
#define WORD_FIVE_HOUR      {6, 0b00001111000}   // row 6, bits 4-7
#define WORD_TWO_HOUR       {6, 0b00000000111}   // row 6, bits 8-10
#define WORD_EIGHT_HOUR     {7, 0b11111000000}   // row 7, bits 0-4
#define WORD_ELEVEN_HOUR    {7, 0b00000111111}   // row 7, bits 5-10
#define WORD_SEVEN_HOUR     {8, 0b11111000000}   // row 8, bits 0-4
#define WORD_TWELVE_HOUR    {8, 0b00000111111}   // row 8, bits 5-10
#define WORD_TEN_HOUR       {9, 0b11100000000}   // row 9, bits 0-2
#define WORD_OCLOCK         {9, 0b00000111111}  // row 10, bits 5-10

// Defining our own datatype to simplify the code
struct Word {
    byte row;
    uint16_t mask;
};

const Word WORDS_AM = WORD_AM;
const Word WORDS_PM = WORD_PM;
const Word WORDS_IT = WORD_IT;
const Word WORDS_IS = WORD_IS;
const Word WORDS_QUARTER_MINUTE = WORD_QUARTER_MINUTE;
const Word WORDS_TWENTY_MINUTE = WORD_TWENTY_MINUTE;
const Word WORDS_FIVE_MINUTE = WORD_FIVE_MINUTE;
const Word WORDS_HALF = WORD_HALF;
const Word WORDS_TEN_MINUTE = WORD_TEN_MINUTE;
const Word WORDS_TO = WORD_TO;
const Word WORDS_PAST = WORD_PAST;
const Word WORDS_NINE_HOUR = WORD_NINE_HOUR;
const Word WORDS_ONE_HOUR = WORD_ONE_HOUR;
const Word WORDS_SIX_HOUR = WORD_SIX_HOUR;
const Word WORDS_THREE_HOUR = WORD_THREE_HOUR;
const Word WORDS_FOUR_HOUR = WORD_FOUR_HOUR;
const Word WORDS_FIVE_HOUR = WORD_FIVE_HOUR;
const Word WORDS_TWO_HOUR = WORD_TWO_HOUR;
const Word WORDS_EIGHT_HOUR = WORD_EIGHT_HOUR;
const Word WORDS_ELEVEN_HOUR = WORD_ELEVEN_HOUR;
const Word WORDS_SEVEN_HOUR = WORD_SEVEN_HOUR;
const Word WORDS_TWELVE_HOUR = WORD_TWELVE_HOUR;
const Word WORDS_TEN_HOUR = WORD_TEN_HOUR;
const Word WORDS_OCLOCK = WORD_OCLOCK;

// Function to alter rowData with new information about which LEDs we want on from each row.
void showWord(const Word& w) {
    rowData[w.row] |= w.mask;
}

// Core function in this mode that caluculates what words to display based on RTC time
void time() {
    
    showWord(WORDS_IT);
    showWord(WORDS_IS);
    
    DateTime now = rtc.now();
    int minute = now.minute();
    int roundedMin = 5 * ((minute) / 5);

    int displayHour24 = now.hour();
    if (roundedMin >= 35) displayHour24 = (displayHour24 + 1) % 24;

    int displayHour = displayHour24 % 12;
    if (displayHour == 0) displayHour = 12;

    // If mode one has just been selected as the desired mode, reset rowData to all off to clear previous data
    if (modeOneChanged) {
        for (int i = 0; i < 11; i++) {
            rowData[i] = MINUTE_BITS_MASK;
        }
        modeOneChanged = false;
        previousRoundedMin = roundedMin;
    }

    // If the minute has changed, reset rowData to all off to clear previous data
    if (previousRoundedMin != roundedMin) {
        for (int i = 0; i < 11; i++) {
            rowData[i] = MINUTE_BITS_MASK;
        }
        previousRoundedMin = roundedMin;
    }

    if (displayHour24 <= 12) {
        showWord(WORDS_AM);
    } else {
        showWord(WORDS_PM);
    }

    // Display the correct word for the minute
    switch (roundedMin) {
        case 0:
            showWord(WORDS_OCLOCK);
        break;
        case 5:
            showWord(WORDS_FIVE_MINUTE);
            showWord(WORDS_PAST);
        break;
        case 10:
            showWord(WORDS_TEN_MINUTE);
            showWord(WORDS_PAST);
        break;
        case 15:
            showWord(WORDS_QUARTER_MINUTE);
            showWord(WORDS_PAST);
        break;
        case 20:
            showWord(WORDS_TWENTY_MINUTE);
            showWord(WORDS_PAST);
        break;
        case 25:
            showWord(WORDS_TWENTY_MINUTE);
            showWord(WORDS_FIVE_MINUTE);
            showWord(WORDS_PAST);
        break;
        case 30:
            showWord(WORDS_HALF);
            showWord(WORDS_PAST);
        break;
        case 35:
            showWord(WORDS_TWENTY_MINUTE);
            showWord(WORDS_FIVE_MINUTE);
            showWord(WORDS_TO);
        break;
        case 40:
            showWord(WORDS_TWENTY_MINUTE);
            showWord(WORDS_TO);
        break;
        case 45:
            showWord(WORDS_QUARTER_MINUTE);
            showWord(WORDS_TO);
        break;
        case 50:
            showWord(WORDS_TEN_MINUTE);
            showWord(WORDS_TO);
        break;
        case 55:
            showWord(WORDS_FIVE_MINUTE);
            showWord(WORDS_TO);
        break;
    }

    // Display the correct word for the hour
    switch (displayHour) {
        case 1:
            showWord(WORDS_ONE_HOUR);
        break;
        case 2:
            showWord(WORDS_TWO_HOUR);
        break;
        case 3:
            showWord(WORDS_THREE_HOUR);
        break;
        case 4:
            showWord(WORDS_FOUR_HOUR);
        break;
        case 5:
            showWord(WORDS_FIVE_HOUR);
        break;
        case 6:
            showWord(WORDS_SIX_HOUR);
        break;
        case 7:
            showWord(WORDS_SEVEN_HOUR);
        break;
        case 8:
            showWord(WORDS_EIGHT_HOUR);
        break;
        case 9:
            showWord(WORDS_NINE_HOUR);
        break;
        case 10:
            showWord(WORDS_TEN_HOUR);
        break;
        case 11:
            showWord(WORDS_ELEVEN_HOUR);
        break;
        case 12:
            showWord(WORDS_TWELVE_HOUR);
        break;
    }

    // If the minute is not a multiple of 5, display the correct LEDs for the leftover minutes
    int leftoverMins = minute % 5;
        for (int i = 0; i <= 11; i++) {
            if (leftoverMins == 1) rowData[i] &= ~0b0001000000000000;
            if (leftoverMins == 2) rowData[i] &= ~0b0011000000000000;
            if (leftoverMins == 3) rowData[i] &= ~0b0111000000000000;
            if (leftoverMins == 4) rowData[i] &= ~0b0111100000000000;
        }
}






// Mode 2 - Snake

// Snake direction
enum Direction { UP, DOWN, LEFT, RIGHT };

// Declaring our own data structure. Each LED has a x and y coordinate.
struct Point {
    byte x;
    byte y;
};

// Deplaring mode-specific variables
Point snakeArray[121];              // Holds the x and y coordinates of each LED in the snake
int snakeLength = 3;                // Initial length of the snake
Direction snakeDirection = UP;      // Initial direction of the snake
unsigned long lastMoveTime = 0;     // Time of last movement
unsigned long moveInterval = 750;   // Delay cooldown between direction changes through touch sensors
Point food;
bool foodExists = false;
static bool snakeInitialized = false;

// Function that spawns snake food if no food is present on the grid
void spawnFood() {
    if (foodExists) return;
    
    // Track all possible empty spots
    bool grid[11][11] = {false};
    
    // Mark snake positions as occupied
    for (int i = 0; i < snakeLength; i++) {
        grid[snakeArray[i].x][snakeArray[i].y] = true;
    }
    
    // Count empty spots
    int emptyCount = 0;
    for (byte y = 0; y < 11; y++) {
        for (byte x = 0; x < 11; x++) {
            if (!grid[x][y]) emptyCount++;
        }
    }
    
    if (emptyCount == 0) return; // No space left
    
    // Pick random empty spot
    int target = random(emptyCount);
    int count = 0;
    
    for (byte y = 0; y < 11; y++) {
        for (byte x = 0; x < 11; x++) {
            if (!grid[x][y]) {
                if (count == target) {
                    food = {x, y};
                    foodExists = true;
                    return;
                }
                count++;
            }
        }
    }
}

// Function that initializes the snake game
void initSnakeGame() {
    snakeLength = 3;
    snakeArray[0] = {5, 7};
    snakeArray[1] = {5, 8};
    snakeArray[2] = {5, 9};

    // Sets the rest of the snake to 255,255 (default / no data)
    for (int i = 3; i < 121; i++) {
        snakeArray[i] = {255, 255};
    }

    snakeDirection = UP;
    food = {5, 3};
    foodExists = true;
    lastMoveTime = millis();
}

// Function that renders the snake game by sending LED information to rowData
void drawSnakeToRowData() {
    // Clear all rows
    for (int i = 0; i < 11; i++) {
        rowData[i] = MINUTE_BITS_MASK;
    }

    // Draw snake (only up to snakeLength)
    for (int i = 0; i < snakeLength; i++) {
        if (snakeArray[i].x < 11 && snakeArray[i].y < 11) {
            rowData[snakeArray[i].y] |= (1 << (10 - snakeArray[i].x));
        }
    }

    // Draw snake food if present
    if (foodExists) {
        if (food.x < 11 && food.y < 11) {
            rowData[food.y] |= (1 << (10 - food.x));
        }
    }

}

// Core function in this mode that controls the snake game
void snake() {

    // If the snake game has not been initialized, initialize it
    if (!snakeInitialized) {
        initSnakeGame();
        snakeInitialized = true;
    }

    // If a touch sensor is short pressed, change the snake direction
    switch (shortPressedPlate) {
        case 1: if (snakeDirection != DOWN) snakeDirection = UP; break;
        case 2: if (snakeDirection != RIGHT) snakeDirection = LEFT; break;
        case 3: if (snakeDirection != LEFT) snakeDirection = RIGHT; break;
        case 4: if (snakeDirection != UP) snakeDirection = DOWN; break;
    }

    // If the last movement was too recent, return
    if ((millis() - lastMoveTime) < moveInterval) return;
    lastMoveTime = millis();

    // Get the new head of the snake
    Point newHead = snakeArray[0];
    switch (snakeDirection) {
        case UP:    newHead.y = (newHead.y == 0) ? 11 - 1 : newHead.y - 1; break;
        case DOWN:  newHead.y = (newHead.y + 1) % 11; break;
        case LEFT:  newHead.x = (newHead.x == 0) ? 11 - 1 : newHead.x - 1; break;
        case RIGHT: newHead.x = (newHead.x + 1) % 11; break;
    }

    // If the new head is the same position as the any snake segments, the snake has eaten itself
    for (int i = 0; i < snakeLength - 1; i++) {
        if (snakeArray[i].x == newHead.x && snakeArray[i].y == newHead.y) {
            initSnakeGame();
            return;
        }
    }

    // Shift the snake array along by 1 (moves the snake)
    for (int i = snakeLength; i > 0; i--) {
        snakeArray[i] = snakeArray[i - 1];
    }
    snakeArray[0] = newHead;

    // If the new head is the same position as the snake food, increase the snake length and remove the food
    if (newHead.x == food.x && newHead.y == food.y) {
        snakeLength++;
        foodExists = false;
        spawnFood();
    }

    // Render the snake game by sending LED information to rowData
    drawSnakeToRowData();

}





// Mode 3 - Tetris

//Declaring mode-specific variables
static uint16_t tetrisGrid[11] = {0}; // Holds the current state of the tetris grid
static int pieceIndex = 0;            // Index of the current tetromino
static int droppingTetromino_x = 0;   // x coordinate of the dropping tetromino
static int droppingTetromino_y = 0;   // y coordinate of the dropping tetromino
static unsigned long lastDrop = 0;    // Time of last drop
static bool tetrisActive = false;     // True if the tetris game is active
const unsigned long dropDelay = 1000; // Delay between moving the dropping tetromino by one row

// Defining our own datatype to simplify the code
typedef struct {
    byte shape[4][4];
    byte size;
} Tetromino;

// Declaring the tetrominoes
const Tetromino tetrominoes[7] = {
    {{{0,1,0,0},{0,1,0,0},{0,1,0,0},{0,1,0,0}}, 4}, // I
    {{{1,1,0,0},{1,1,0,0},{0,0,0,0},{0,0,0,0}}, 2}, // O
    {{{0,1,0,0},{1,1,1,0},{0,0,0,0},{0,0,0,0}}, 3}, // T
    {{{0,1,1,0},{1,1,0,0},{0,0,0,0},{0,0,0,0}}, 3}, // S
    {{{1,1,0,0},{0,1,1,0},{0,0,0,0},{0,0,0,0}}, 3}, // Z
    {{{1,0,0,0},{1,1,1,0},{0,0,0,0},{0,0,0,0}}, 3}, // J
    {{{0,0,1,0},{1,1,1,0},{0,0,0,0},{0,0,0,0}}, 3}  // L
};

// Check if piece can be placed at (x, y)
bool canPlaceTetromino(int x, int y, const Tetromino& t, uint16_t grid[]) {
    for (int row = 0; row < t.size; row++) {
        for (int col = 0; col < t.size; col++) {
            if (t.shape[row][col]) {
                int gx = x + col;
                int gy = y + row;
                if (gx < 0 || gx >= 11 || gy >= 11) return false;
                if (gy >= 0 && (grid[gy] & (1 << (10 - gx)))) return false;
            }
        }
    }
    return true;
}

// Lock piece into grid
void lockTetromino(int x, int y, const Tetromino& t, uint16_t grid[]) {
    for (int row = 0; row < t.size; row++) {
        for (int col = 0; col < t.size; col++) {
            if (t.shape[row][col]) {
                int gx = x + col;
                int gy = y + row;
                if (gx >= 0 && gx < 11 && gy >= 0 && gy < 11) {
                    grid[gy] |= (1 << (10 - gx));
                }
            }
        }
    }
}

// Clear completed lines
void clearTetrominoRow(uint16_t grid[]) {
    for (int y = 11-1; y >= 0; y--) {
        if ((grid[y] & 0x07FF) == 0x07FF) {  // all columns filled
            for (int j = y; j > 0; j--) {
                grid[j] = grid[j - 1];
            }
            grid[0] = 0;
            y++;
        }
    }
}
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
void loop() {

    shortPressedPlate = 0;
    bool plateOne = (digitalRead(plateone) == LOW);
    bool plateTwo = (digitalRead(platetwo) == LOW);
    bool plateThree = (digitalRead(platethree) == LOW);
    bool plateFour = (digitalRead(platefour) == LOW);

    int newPlate = 0;
    if (plateOne) newPlate = 1;
    else if (plateTwo) newPlate = 2;
    else if (plateThree) newPlate = 3;
    else if (plateFour) newPlate = 4;

    // If a new plate is pressed, handle the press
    if (newPlate != 0) {
        // If the new plate is different from the last plate, handle the press
        if (newPlate != lastPlate) {
            pressStart = millis();
            longPressHandled = false;
        } else {
            // If the new plate is the same as the last plate, and the press has been held for longer than 2 seconds, change the mode
            if (!longPressHandled && millis() - pressStart >= 2000) {
                for (int i = 0; i < 11; i++) {
                    rowData[i] = MINUTE_BITS_MASK;
                }

                // Mode is changed; reset the mode-specific variables
                modeOneChanged = true;
                snakeInitialized = false;
                tetrisActive = false;
                scrollInitialized = false;
                glitchInitialized = false;
                rainInitialized = false;
                conwayInitialized = false;

                // Set the new mode
                mode = (mode == newPlate) ? 0 : newPlate;
                longPressHandled = true;

                // If the new mode is not 0, turn on the logo
                if (mode != 0) {
                    digitalWrite(starpin, HIGH);
                } else {
                    digitalWrite(starpin, LOW);
                }
                
            }
        }
    } else {
        // If the last plate is not 0, and the press has not been long pressed, set the shortPressedPlate to the pressed plate
        if (lastPlate != 0 && !longPressHandled) {
            shortPressedPlate = lastPlate;
        }
    }

    // Set the last plate to the new plate
    lastPlate = newPlate;

    // If the mode is 4 and a touch sensor is pressed, change the active effect
    if (mode == 4 && shortPressedPlate != 0) {
        if (shortPressedPlate == 1) {
            activeEffect = 1;
        } else if (shortPressedPlate == 2) {
            activeEffect = 2;
        } else if (shortPressedPlate == 3) {
            activeEffect = 3;
        } else if (shortPressedPlate == 4) {
            activeEffect = 4;
        }
        // Reset the mode-specific variables
        scrollInitialized = false;
        glitchInitialized = false;
        rainInitialized = false;
        conwayInitialized = false;
    }

    // Run the mode-specific function
    switch (mode) {
        case 1:
            time();
            break;
        case 2:
            snake();
            break;
        case 3:
            tetris();
            break;
        case 4:
            miscellaneous();
            break;
        default:
            break;
    }
}
